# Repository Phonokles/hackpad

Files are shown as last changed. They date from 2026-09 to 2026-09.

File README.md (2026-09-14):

# ascii-emotion-controller

A macropad for switching the expressions of my ASCII character while
streaming or recording. Built for Hack Club Stardance.

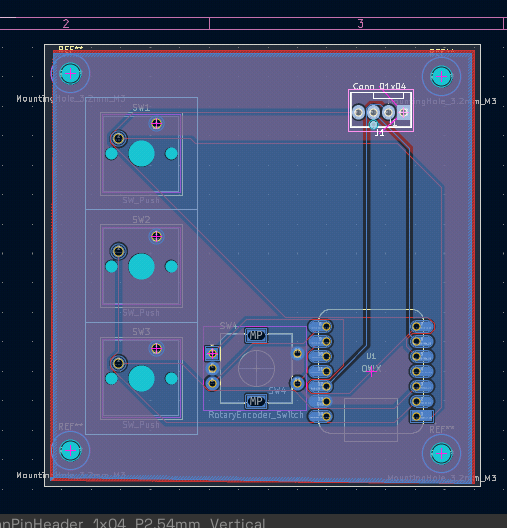
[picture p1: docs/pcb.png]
PCB


## Why

I have a small face tracking app that renders an ASCII face and animates it
from my webcam and mic. The face sits on top of my stream in OBS, so the
browser window is never the focused one. Keystrokes always land somewhere
else, no matter what I press.

So the hackpad does not show up as a keyboard. It sends lines over USB
serial instead, and the page reads them with WebSerial. That works no matter
which window is in front.

## What is in it

* Seeed XIAO RP2040
* 3 Cherry MX switches
* 1 EC11 rotary encoder with push button
* 1 SSD1306 OLED, 0.91 inch, 128x32, over I2C
* 74 x 75 mm, two layers, solid ground pour
* Case is two printed parts, held together with M3 heatset inserts

Full part list in [BOM.csv](BOM.csv).

## Case

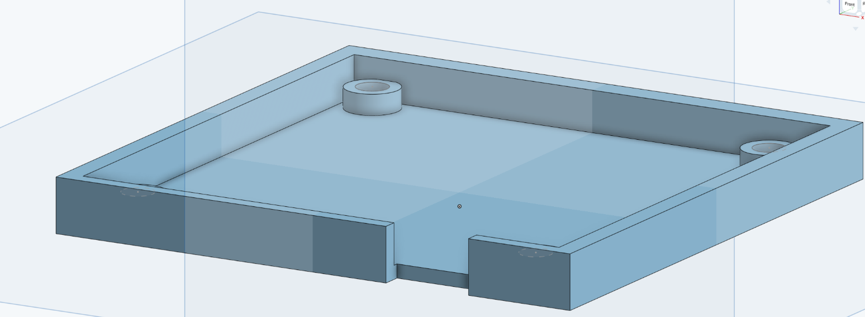
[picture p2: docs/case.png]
Case base

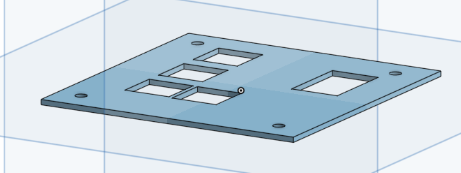
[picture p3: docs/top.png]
Top plate


The base is a 8 mm tray with four 3 mm posts that hold the board off the
floor so the solder joints have room. The top plate is 1.5 mm thick around
the switch cutouts, which is what MX clips need to snap in.

## Controls

| Input | does |
| --- | --- |
| SW1 | normal `[+_+]` |
| SW2 | laughing `[*_*]` |
| SW3 | bored `[-_-]` |
| Turn wheel | opens the menu on the OLED |
| Press wheel in menu | confirm selection |
| Hold wheel | mouth keeps moving even when I am quiet |

The menu has auto, normal, laughing, bored, record and transparent.

## Protocol

The XIAO sends one line per event:

```
READY:hackpad
DOWN:btn1
UP:btn1
EXPR:laughing
ACT:record
```

## Repo layout

```
production/
  gerbers/      board files for the fab
  cad/          case as STEP and STL
  firmware/     boot.py and code.py
hardware/       KiCad project
web/            the face tracking page
docs/           renders and photos
BOM.csv
```

## Setup

### Firmware

Flash CircuitPython onto the XIAO, then copy `boot.py` and `code.py` from
`production/firmware/` to the root of the CIRCUITPY drive.

From the Adafruit library bundle into `CIRCUITPY/lib/`:

* `adafruit_displayio_ssd1306.mpy`
* `adafruit_display_text/`

`keypad`, `rotaryio` and `usb_cdc` are already built in.

### Website

Needs a local server, because ES modules fail CORS over `file://`:

```
cd web
python -m http.server 8000
```

Open `http://localhost:8000` and click the connect button in the bottom
right corner. The browser asks for permission once and remembers it.

Needs Chromium or Chrome. Firefox has no WebSerial.

On Linux your user needs access to `/dev/ttyACM0`. On Arch:

```
sudo usermod -aG uucp $USER
```

Log out and back in afterwards.

### Hardware

KiCad 9 or newer, project in `hardware/`.

The case prints without support. STEP files are in `production/cad/` if you
want to change something, STL next to them for printing straight away.

## Known things

* The OBS browser source cannot do WebSerial. The page runs in a Chromium
  window and OBS picks it up with a window capture.
* Chromium freezes tabs that are fully hidden, so the window has to stay
  visible somewhere. I keep it on its own workspace.
* The display footprint is drawn for a 1.3 inch module but a 0.91 inch one
  goes in. The four pads line up, the printed outline is just a bit large.

## License

MIT

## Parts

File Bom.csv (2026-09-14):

Reference | Quantity | Component | Description | Footprint | Notes
U1 | 1 | Seeed XIAO RP2040 | Main microcontroller board | XIAO-Generic-Hybrid-14P | Through hole headers
SW1-SW3 | 3 | Cherry MX switch | Mechanical key switch | SW_Cherry_MX_1.00u_PCB | 19.05 mm spacing
SW4 | 1 | ALPS EC11 rotary encoder | Incremental encoder with push button | RotaryEncoder_Alps_EC11E-Switch_Vertical_H20mm | 5 pins plus 2 mounting tabs
J1 | 1 | Pin header 1x04 2.54 mm | Connector for the OLED module | PinHeader_1x04_P2.54mm_Vertical | Pin order GND-VCC-SCL-SDA
J1 | 1 | SSD1306 OLED 0.91 inch | 128x32 I2C display module | - | Plugs into J1
- | 3 | Keycap MX | Caps for the three switches | - | -
- | 1 | Encoder knob | Knob for the EC11 shaft | - | 6 mm shaft
- | 4 | M3 heatset insert | Threaded insert for the case | - | 4.7 mm hole 4 mm deep
- | 4 | M3 screw 8 mm | Holds the top plate to the base | - | 3.4 mm clearance holes
- | 1 | PCB | 74 x 75 mm two layer board | - | See production/gerbers
- | 1 | Case base | 2D printed | - | production/cad
- | 1 | Case top plate | 3D printed | - | 1.5 mm around switch cutouts
- | 1 | USB-C cable | Data cable for the XIAO | - | Must carry data not only power

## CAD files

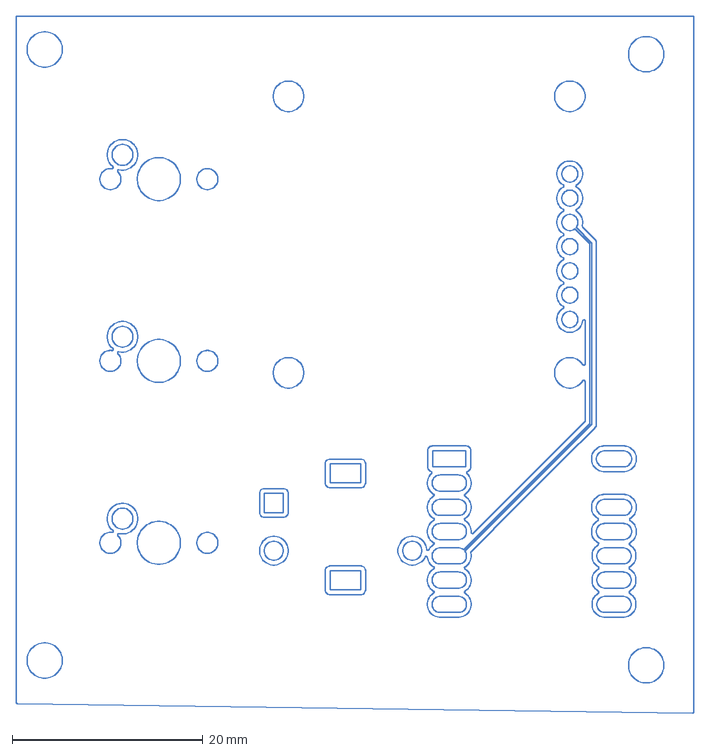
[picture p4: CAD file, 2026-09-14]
plots/hackpad4-B_Cu.dxf
71.0 x 73.0 mm

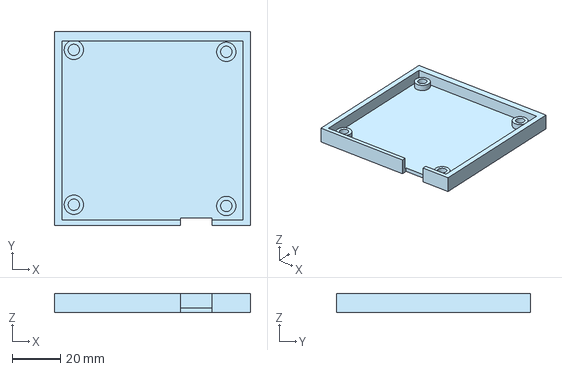
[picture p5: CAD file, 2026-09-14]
production/cad/hackpad-base.step
81.0 x 80.0 x 8.00 mm

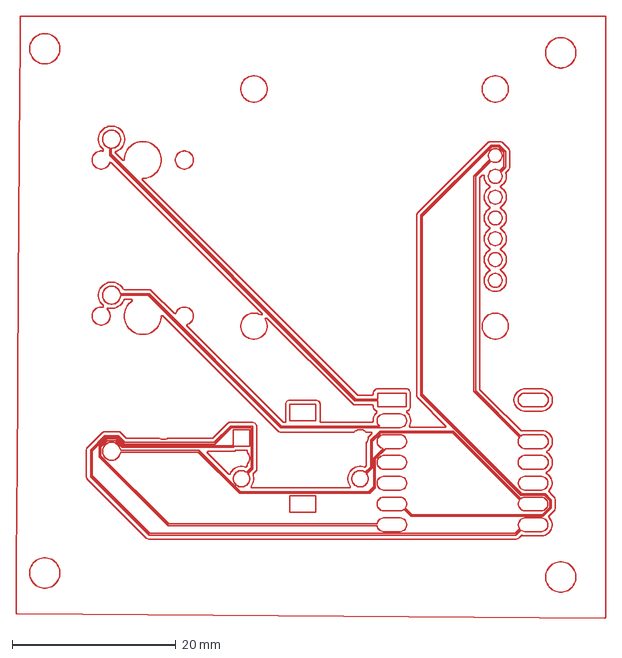
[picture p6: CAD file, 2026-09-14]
plots/hackpad4-F_Cu.dxf
72.0 x 73.5 mm

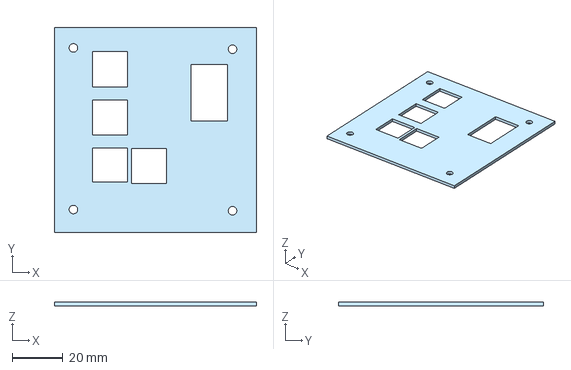
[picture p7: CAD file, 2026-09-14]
production/cad/hackpad-top.step
80.0 x 81.0 x 1.50 mm

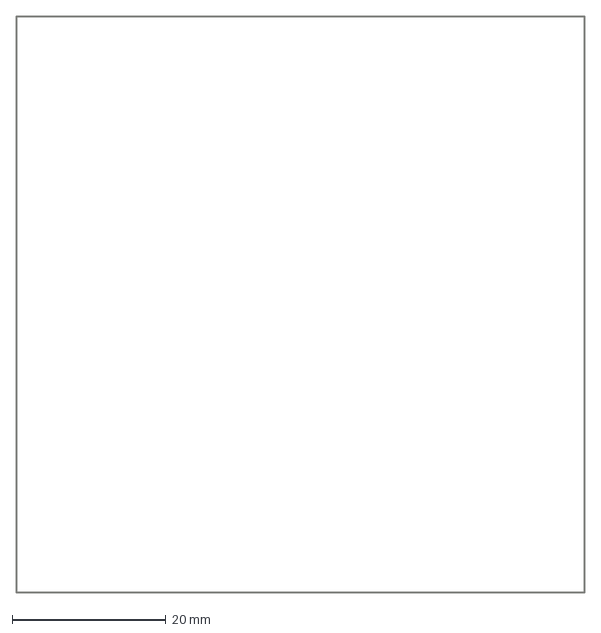
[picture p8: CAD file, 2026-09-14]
plots/hackpad4-Edge_Cuts.dxf
74.1 x 75.0 mm

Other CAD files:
plots/hackpad4-B_Mask.dxf
plots/hackpad4-B_Paste.dxf
plots/hackpad4-B_Silkscreen.dxf
plots/hackpad4-F_Mask.dxf
plots/hackpad4-F_Paste.dxf
plots/hackpad4-F_Silkscreen.dxf
production/cad/hackpad-base.stl
production/cad/hackpad-top.stl

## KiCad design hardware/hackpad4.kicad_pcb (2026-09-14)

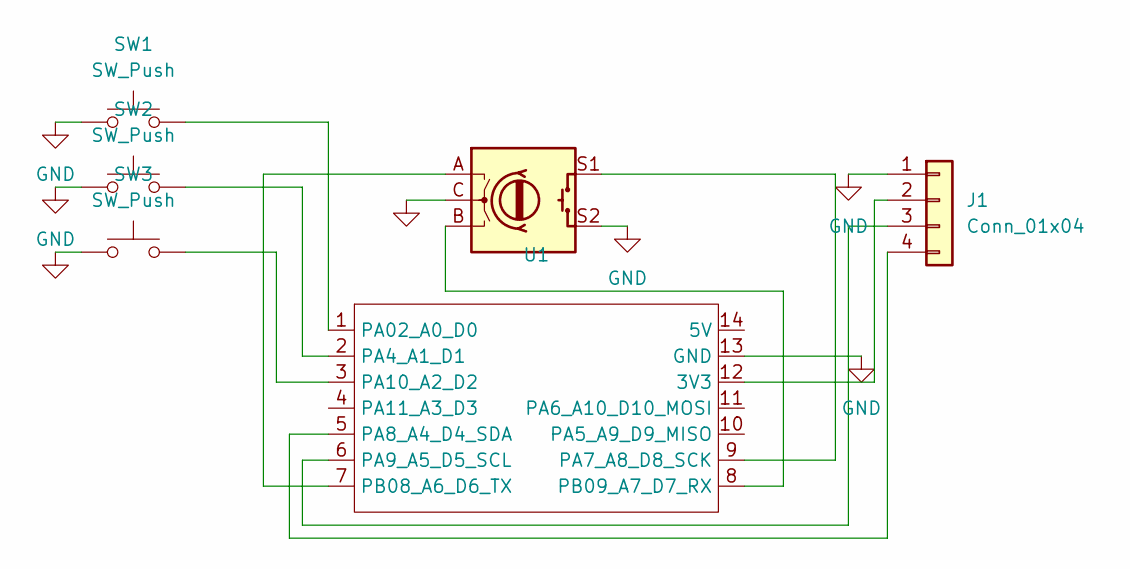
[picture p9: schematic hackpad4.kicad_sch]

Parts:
J1: Conn_01x04; FanPinHeader_1x04_P2.54mm_Vertical
SW1, SW2, SW3: SW_Push; SW_Cherry_MX_1.00u_PCB
SW4: RotaryEncoder_Switch; RotaryEncoder_Alps_EC11E-Switch_Vertical_H20mm
U1: MOUDLE-SEEEDUINO-XIAO; XIAO-Generic-Hybrid-14P-2.54-21X17.8MM

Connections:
GND: J1.1, SW1.1, SW2.1, SW3.1, SW4.C, SW4.S2, U1.13 (GND)
unnamed: J1.2, U1.12 (3V3)
unnamed: J1.3, U1.6 (PA9_A5_D5_SCL)
unnamed: J1.4, U1.5 (PA8_A4_D4_SDA)
unnamed: SW1.2, U1.1 (PA02_A0_D0)
unnamed: SW2.2, U1.2 (PA4_A1_D1)
unnamed: SW4.S1, U1.9 (PA7_A8_D8_SCK)
unnamed: SW3.2, U1.3 (PA10_A2_D2)
unnamed: SW4.A, U1.7 (PB08_A6_D6_TX)
unnamed: SW4.B, U1.8 (PB09_A7_D7_RX)

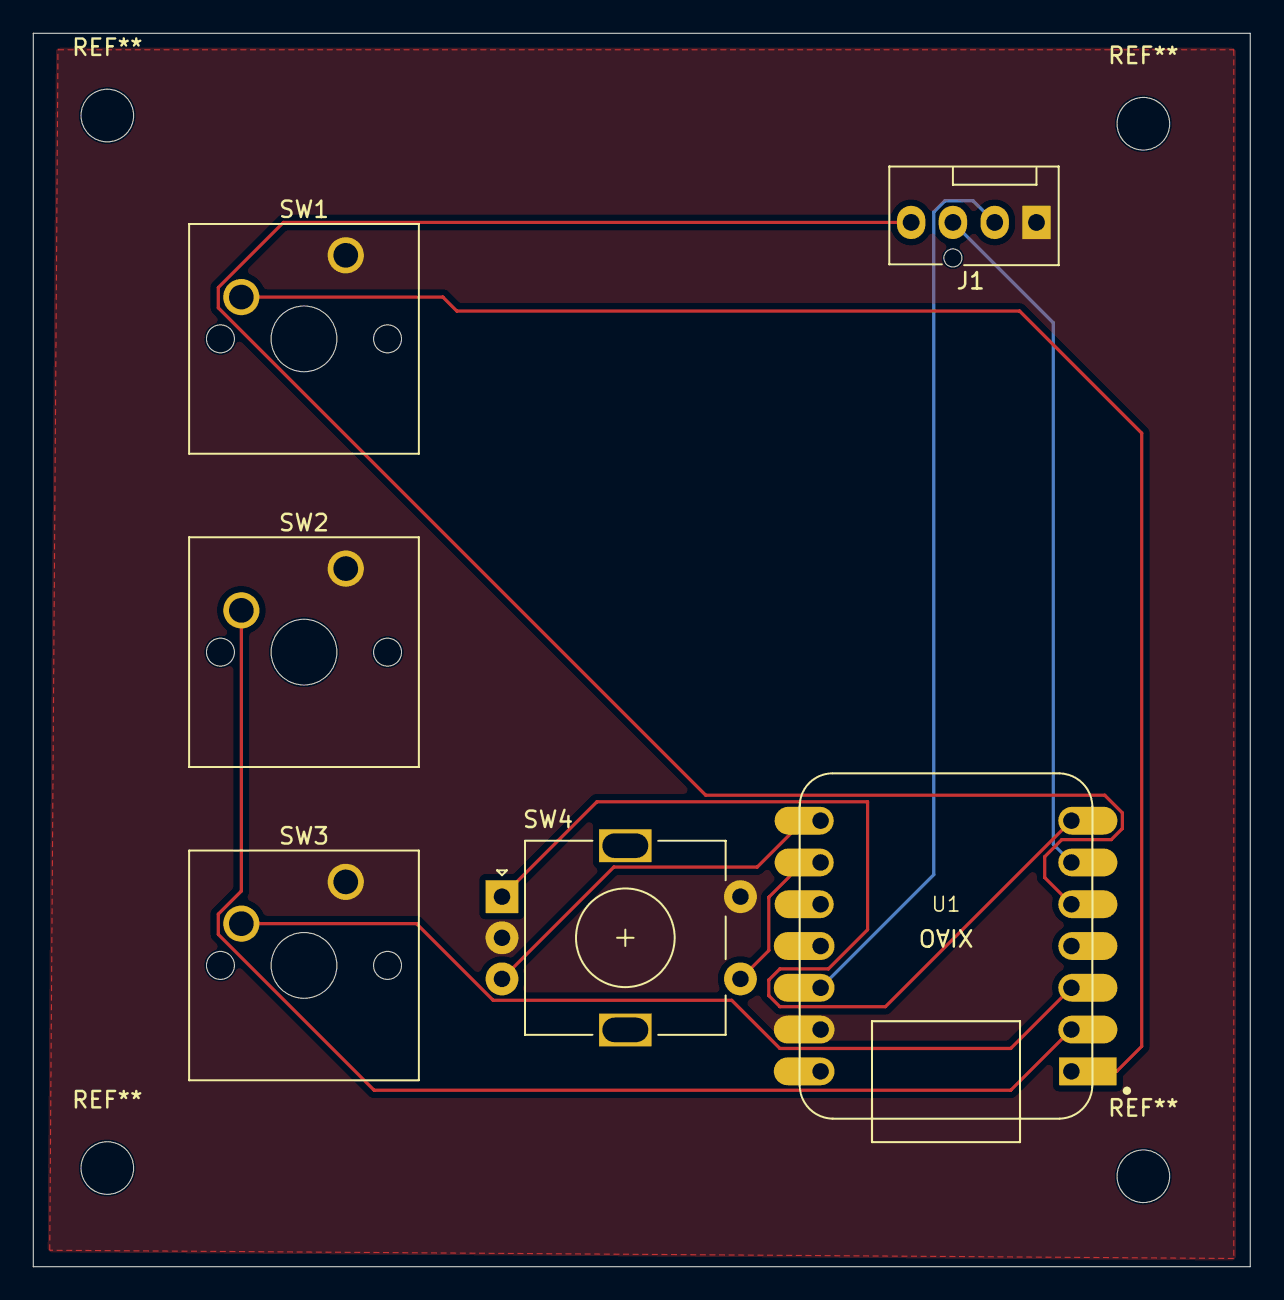
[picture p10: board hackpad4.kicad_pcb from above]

Board: 2 copper layers, 74.0 x 75.0 mm, 6 parts (0 on the bottom side), 10 nets.

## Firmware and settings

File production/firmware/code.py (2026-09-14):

import time

import board
import busio
import displayio
import keypad
import rotaryio
import terminalio
import usb_cdc

import adafruit_displayio_ssd1306
from adafruit_display_text import label

try:
    from i2cdisplaybus import I2CDisplayBus
except ImportError:
    from displayio import I2CDisplay as I2CDisplayBus


MENU = [
    ("auto",        "ACT",  "auto"),
    ("normal",      "EXPR", "normal"),
    ("lachen",      "EXPR", "laughing"),
    ("genervt",     "EXPR", "bored"),
    ("aufnahme",    "ACT",  "record"),
    ("transparent", "ACT",  "transparent"),
]

BUTTON_NAMES = ["btn1", "btn2", "btn3"]

MENU_TIMEOUT = 4.0


displayio.release_displays()

i2c = busio.I2C(board.D5, board.D4)
display_bus = I2CDisplayBus(i2c, device_address=0x3C)
display = adafruit_displayio_ssd1306.SSD1306(display_bus, width=128, height=32)

encoder = rotaryio.IncrementalEncoder(board.D0, board.D1)

# reihenfolge: SW1, SW2, SW3, encoder knopf
keys = keypad.Keys(
    (board.D10, board.D9, board.D8, board.D2),
    value_when_pressed=False,
    pull=True,
)
ENCODER_KEY = 3


group = displayio.Group()
lines = []
for row in range(3):
    text_line = label.Label(terminalio.FONT, text="", x=2, y=6 + row * 11)
    group.append(text_line)
    lines.append(text_line)
display.root_group = group


def show(row0="", row1="", row2=""):
    lines[0].text = row0
    lines[1].text = row1
    lines[2].text = row2


def draw_idle():
    show("   [ +_+ ]", "", "rad = menue")


def draw_talk():
    show("   [ +.+ ]", "", "reden...")


def draw_menu(selected):
    # fenster von drei eintraegen um die auswahl rum
    start = max(0, min(selected - 1, len(MENU) - 3))
    rows = []
    for offset in range(3):
        index = start + offset
        if index >= len(MENU):
            rows.append("")
            continue
        marker = ">" if index == selected else " "
        rows.append("{} {}".format(marker, MENU[index][0]))
    show(*rows)


def send(kind, value):
    if usb_cdc.data is None:
        return
    usb_cdc.data.write("{}:{}\n".format(kind, value).encode("utf-8"))


menu_open = False
selected = 0
last_position = encoder.position
last_activity = time.monotonic()

draw_idle()
send("READY", "hackpad")

while True:
    now = time.monotonic()

    position = encoder.position
    if position != last_position:
        delta = position - last_position
        last_position = position
        last_activity = now

        # erste drehung macht nur das menue auf
        if not menu_open:
            menu_open = True
        else:
            selected = (selected + delta) % len(MENU)

        draw_menu(selected)

    event = keys.events.get()
    if event is not None:
        last_activity = now

        if event.key_number == ENCODER_KEY:
            if menu_open:
                if event.pressed:
                    kind, value = MENU[selected][1], MENU[selected][2]
                    send(kind, value)
                    menu_open = False
                    show("", "  " + MENU[selected][0], "")
                    time.sleep(0.5)
                    draw_idle()
            else:
                # menue zu: knopf halten laesst den mund wackeln
                if event.pressed:
                    send("DOWN", "encoder")
                    draw_talk()
                else:
                    send("UP", "encoder")
                    draw_idle()
        else:
            name = BUTTON_NAMES[event.key_number]
            send("DOWN" if event.pressed else "UP", name)

    if menu_open and now - last_activity > MENU_TIMEOUT:
        menu_open = False
        draw_idle()

    time.sleep(0.005)
